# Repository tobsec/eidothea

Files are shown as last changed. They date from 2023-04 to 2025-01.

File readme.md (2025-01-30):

# EIDOTHEA

Board is developed to run a V8 Chevy Small Block engine fully sequential and provide some room to adapt for other applications.
The design is based on Proteus to be able to share the same [rusEFI](https://github.com/rusefi/rusefi) firmware.
See more details and pictures in the rusEFI Forum: [https://www.rusefi.com/forum/viewtopic.php?t=2559](https://www.rusefi.com/forum/viewtopic.php?t=2559)

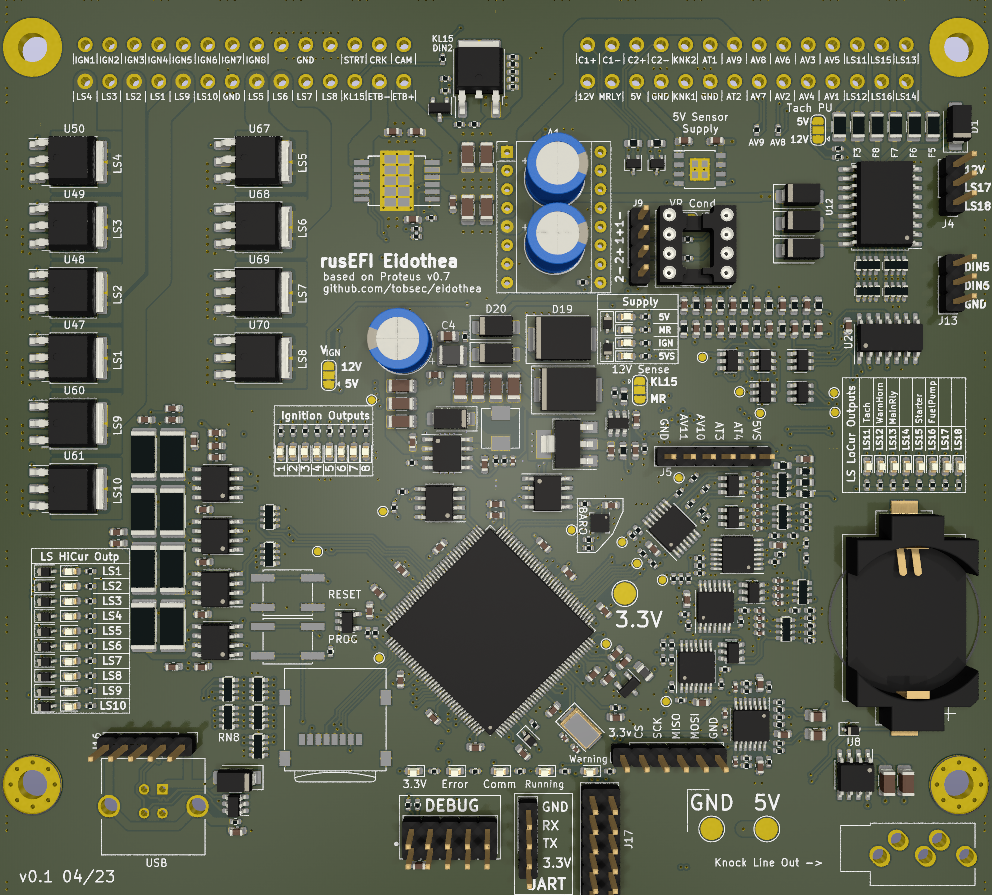
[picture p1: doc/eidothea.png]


# Hardware Features

## Microcontroller

- STM32F427ZGT6
    - 180 MHz ARM Cortex-M4
    - 1MB flash
    - 256 KB SRAM
    - LQFP144 package

- Also fully compatible with several STM32F7 parts, including the STM32F767ZI, used on v0.1 and v0.2, as well as STM32F429ZIT6.

## Connectors

Sicma 56 connector and weatherproof case available at [AliExpress](https://aliexpress.com/item/32857771975.html)

## Connectivity

- 2x CAN bus
- USB 2.0 full speed (12 mbit/s), on-board or wired to connector for sealed applications
- [10-pin, 2.54mm Cortex debug header](http://infocenter.arm.com/help/topic/com.arm.doc.faqs/attached/13634/cortex_debug_connectors.pdf)

## Outputs

- 10x 7A low-side outputs
- 8x 0.5A low-side outputs (2x internal)
- 8x 5V ignition (or general purpose) outputs
- H-bridge for electronic throttle (can use external A4988 stepper module alternatively)

## Inputs

- 11x Analog voltage inputs (2x internal)
- 4x Analog temperature (5V pullup) inputs (2x internal)
- 2x VR crank/cam/vehicle speed inputs via adapter board
- 6x hall cam/crank or digital input (2x internal)
- 2x onboard knock sensing

## Power Supply

- Full operation from 6-24v supply
- Limited operation from 4-6v
- 5V sensor supply, 150mA, fully protected

## For generating JLC PCB files install adapted KiCad Plugin
https://github.com/tobsec/JLC-Plugin-for-KiCad/tree/2.3.0-adapt

## Known issues
- Main relay can only be powered from a high current low-side output (don't run it as documented from a low-side output LS13, it will not work as the relay coil always back feeds some power to the 12V_MR rail)

## Pinout considerations
- Rework analog voltage input 2 (AV2) from pull-down to 2.7k pull-up for using it as a third external temperature sensor input (AT)
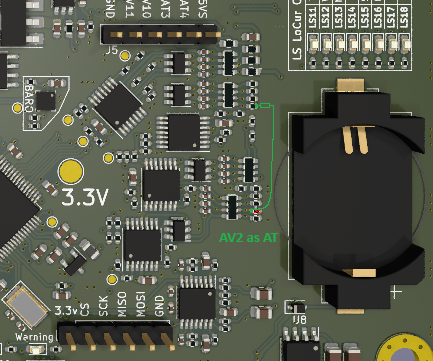
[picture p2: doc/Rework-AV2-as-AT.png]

- Rework digital input 3 (DIGITAL_3) from pull-up to pull-down to use it for starter button/switch
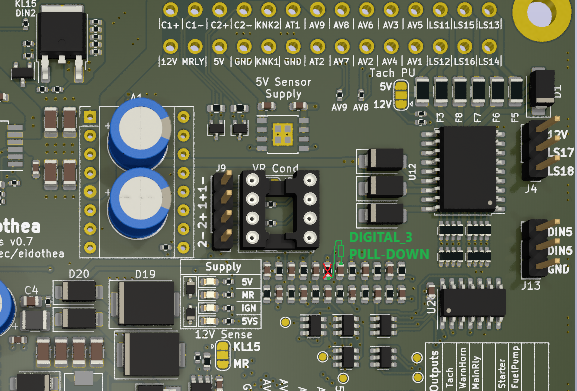
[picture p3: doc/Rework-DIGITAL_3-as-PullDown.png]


## Pinout
| No. | Pin | Description | IN / OUT | Function | Type | Drive / Signal Voltage | Notes |
|-----|---|---|---|---|---|---|---|
| 1 | IGN1 | Ignition Trigger 1 | OUT | Gate Driver IC | Low Current | 5V / 12V_MR | Default 5V |
| 2 | IGN2 | Ignition Trigger 2 | OUT | Gate Driver IC | Low Current | 5V / 12V_MR | Default 5V |
| 3 | IGN3 | Ignition Trigger 3 | OUT | Gate Driver IC | Low Current | 5V / 12V_MR | Default 5V |
| 4 | IGN4 | Ignition Trigger 4 | OUT | Gate Driver IC | Low Current | 5V / 12V_MR | Default 5V |
| 5 | IGN5 | Ignition Trigger 5 | OUT | Gate Driver IC | Low Current | 5V / 12V_MR | Default 5V |
| 6 | IGN6 | Ignition Trigger 6 | OUT | Gate Driver IC | Low Current | 5V / 12V_MR | Default 5V |
| 7 | IGN7 | Ignition Trigger 7 | OUT | Gate Driver IC | Low Current | 5V / 12V_MR | Default 5V |
| 8 | IGN8 | Ignition Trigger 8 | OUT | Gate Driver IC | Low Current | 5V / 12V_MR | Default 5V |
| 9 | GND | GND | IN | Supply | - | - | - |
| 10  | GND | GND | IN | Supply | - | - | - |
| 11  | GND | GND | IN | Supply | - | - | - |
| 12  | DIGITAL_3 | Start Switch/Button Signal | IN | Digital In 12V | Schmitt Trigger  | PullDown | Rework to PullDown |
| 13  | DIGITAL_VR_1 | Crank Sensor | IN | HALL / VR In | Schmitt Trigger  | PullUp 5V | Default HALL (opt. VR Cond. Circuit) |
| 14  | DIGITAL_VR_4 | Cam Sensor | IN | HALL / VR In | Schmitt Trigger  | PullUp 5V | Default HALL (opt. VR Cond. Circuit) |
| 15  | LS4 | Injector 4 | OUT | Low Side Switch | High Current 7A  | - | - |
| 16  | LS3 | Injector 3 | OUT | Low Side Switch | High Current 7A  | - | - |
| 17  | LS2 | Injector 2 | OUT | Low Side Switch | High Current 7A  | - | - |
| 18  | LS1 | Injector 1 | OUT | Low Side Switch | High Current 7A  | - | - |
| 19  | LS9 | Spare (e.g. Boost Control) | OUT | Low Side Switch | High Current 7A  | - | - |
| 20  | LS10 | Main Relay Drive | OUT | Low Side Switch | High Current 7A  | - | - |
| 21  | GND | Knock Sensor 2 - | IN | Knock Sensing | - | - | - |
| 22  | LS5 | Injector 5 | OUT | Low Side Switch | High Current 7A  | - | - |
| 23  | LS6 | Injector 6 | OUT | Low Side Switch | High Current 7A  | - | - |
| 24  | LS7 | Injector 7 | OUT | Low Side Switch | High Current 7A  | - | - |
| 25  | LS8 | Injector 8 | OUT | Low Side Switch | High Current 7A  | - | - |
| 26  | 12V_RAW (+ DIGITAL_2) | Ignition (KL15) | IN | Supply | - | - | |
| 27  | ETB1- | ETB M- / Idle Stepper A2 | OUT | H Bridge (opt. Stepper) | - | - | - |
| 28  | ETB1+ | ETB M+ / Idle Stepper A1 | OUT | H Bridge (opt. Stepper) | - | - | - |
| 29  | CAN+ | CAN1 H | IN / OUT | O2 Sensor CAN (500kbps) | - | - | Internal 120 Ohm CAN Termination R |
| 30  | CAN- | CAN1 L | IN / OUT | O2 Sensor CAN (500kbps) | - | - | Internal 120 Ohm CAN Termination R |
| 31  | CAN2+ | CAN2 H | IN / OUT | NMEA2000 CAN (250kbps)  | - | - | Internal 120 Ohm CAN Termination R |
| 32  | CAN2- | CAN2 L | IN / OUT | NMEA2000 CAN (250kbps)  | - | - | Internal 120 Ohm CAN Termination R |
| 33  | KNOCK_2 | Knock Sensor 2 + | IN | Knock Sensing | - | - | - |
| 34  | AT1 | Water Temperature Sensor | IN | Analog Temp | - | - | - |
| 35  | AV9 | PPS2 (Idle Stepper B2) | IN (OUT) | Analog  (opt. Stepper)  | - | - | Default Pedal Position Sensor 2 |
| 36  | AV8 | PPS1 (Idle Stepper B1) | IN (OUT) | Analog  (opt. Stepper)  | - | - | Default Pedal Position Sensor 1 |
| 37  | AV6 | ETB TPS2 | IN | Analog Voltage | - | - | - |
| 38  | AV3 | Water Pressure Sensor | IN | Analog Voltage | - | - | - |
| 39  | AV5 | ETB TPS1 | IN | Analog Voltage | - | - | - |
| 40  | LS11_F | Tacho Out | OUT | Low Side + PullUp | Low Current 0.5A | 5V / 12V_MR | Default PullUp to 12V_MR |
| 41  | LS15_F | Starter Relay Drive | OUT | Low Side Switch | Low Current 0.5A | - | - |
| 42  | LS13_F | ~Main Relay Drive~ Spare | OUT | Low Side Switch | Low Current 0.5A | - | Don't use for MR! |
| 43  | 12V_MR | Power (from Main Relay) | IN | Supply | - | - | - |
| 44  | 12V_MR | Power (from Main Relay) | IN | Supply | - | - | - |
| 45  | 5V_SENSOR_1 | Sensor Supply 5V | OUT | Analog Supply 150mA | - | - | - |
| 46  | GND | Sensor GND | OUT | Analog GND | - | - | - |
| 47  | KNOCK_1 | Knock Sensor 1 + | IN | Knock Sensing | - | - | - |
| 48  | GND | Knock Sensor 1 - | IN | Knock Sensing | - | - | - |
| 49  | AT2 | Oil Temperature Sensor | IN | Analog Temp | - | - | - |
| 50  | AV7 | Fuel Pressure Sensor | IN | Analog Voltage | - | - | - |
| 51  | AV2 | IAT Sensor | IN | Analog ~Voltage~ Temp | - | - | Rework PullUp for Temp Sensing |
| 52  | AV4 | Oil Pressure Sensor | IN | Analog Voltage | - | - | - |
| 53  | AV1 | MAP Sensor | IN | Analog Voltage | - | - | - |
| 54  | LS12_F | Audio Warning Horn / MIL | OUT | Low Side Switch | Low Current 0.5A | - | - |
| 55  | LS16_F | Fuel Pump Relay Drive | OUT | Low Side Switch | Low Current 0.5A | - | - |
| 56  | LS14_F | Spare (e.g. Boost Control) | OUT | Low Side Switch | Low Current 0.5A | - | - |

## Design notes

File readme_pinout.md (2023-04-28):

# Eidothea Pinout & Wiring

1	IGN1
2	IGN2
3	IGN3
4	IGN4
5	IGN5
6	IGN6
7	IGN7
8	IGN8
9	GND
10	GND
11	GND
12	DIGITAL_3
13	DIGITAL_VR_1
14	DIGITAL_VR_4
15	LS4
16	LS3
17	LS2
18	LS1
19	LS9
20	LS10
21	GND
22	LS5
23	LS6
24	LS7
26	12V_RAW + DIGITAL_2
27	ETB1-
28	ETB1+
28	LS8
29	CAN+
30	CAN-
31	CAN2+
32	CAN2-
33	KNOCK_2
34	AT1
35	AV9
36	AV8
37	AV6
38	AV3
39	AV5
40	LS11_F
41	LS15_F
42	LS13_F
43	12V_MR
44	12V_MR
45	5V_SENSOR_1
46	GND
47	KNOCK_1
48	GND
49	AT2
50	AV7
51	AV2
52	AV4
53	AV1
54	LS12_F
55	LS16_F
56	LS14_F

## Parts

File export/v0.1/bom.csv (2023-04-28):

Designator | Footprint | Quantity | Value | LCSC Part #
BT1 | BatteryHolder_Keystone_1060_1x2032 | 1 | Battery_Cell | C70377
C1, C109, C6 | CP_Radial_D8.0mm_P3.50mm | 3 | 56u | C106564
C10, C100, C101, C110, C31, C41, C42, C43, C48, C53, C58, C63, C64, C65, C66, C69, C70, C71, C72, C73, C75, C81, C83, C85, C92, C94, C95 | 0603 | 27 | 100n | C14663
C102, C103, C104, C105, C15, C36, C8, C88, C89, C96, C97, C98, C99 | 0603 | 13 | 10n | C57112
C106, C7 | 1206 | 2 | 2.2u | C170101
C107, C108, C12, C13, C24, C25, C87, C9, C90, C91, C93 | 1206 | 11 | 10u | C13585
C11, C20, C21 | 0402 | 3 | 330p | C13533
C111, C2, C3, C30, C5, C86 | 0603 | 6 | 1u | C15849
C14, C67, C68, C74, C78, C82, C84 | 0603 | 7 | 4.7u | C19666
C16, C17 | 0805 | 2 | 3.3n | C107149
C18, C19 | 0603 | 2 | 680p | C1630
C22, C23 | 0402 | 2 | 47p | C1567
C26, C27, C28, C29, C32, C33, C34, C35, C37, C38, C39, C40 | 0603 | 12 | 1n | C1588
C4 | 0805 | 1 | 4.7u | C98192
C44, C45, C46, C47, C49, C50, C51, C52, C54, C55, C56, C57, C59, C60, C61, C62 | 0402 | 16 | 100n | C1525
C76, C77 | 0402 | 2 | 33p | C1562
C79, C80 | 0603 | 2 | 2.2u | C23630
D1, D17, D2, D3, D4, D6, D7 | D_SMA | 7 | D_Schottky | C14996
D10, D11 | D_SOD-323 | 2 | 1N5819WS | C191023
D12, D15, D21, D22, D23, D24 | 0603 | 6 | GREEN | C72043
D13, U30, U31, U32, U33, U35, U37, U55, U56, U57, U58, U71, U74, U77, U80, U83, U86, U89, U92 | 0603 | 19 | RED | C2286
D14, U72, U75, U78, U81, U84, U87, U90, U93 | 0603 | 9 | BLUE | C72041
D16 | 0603 | 1 | ORANGE | C72038
D18, U13, U15, U17, U19, U21, U23 | SOT-23-6 | 7 | SRV05-4 | C85364
D19, D5 | D_SMC | 2 | SM15T33CA | C406701
D8, D9 | SOT-323_SC-70 | 2 | PESD1CAN-UX | C152727
F3, F4, F5, F6, F7, F8 | 1206 | 6 | Polyfuse | C207035
FB1 | 0805 | 1 | Ferrite_Bead | C1015
J10 | microSD_HC_Wuerth_693072010801 | 1 | Micro_SD_Card | C164170
J14 | USB_B_921-111A1010Y10200_Vertical | 1 | USB_B | C26234
J7 | Jack_3.5mm_PJ-3250-5A | 1 | AudioJack3 | C165947
L1 | 1210 | 1 | 2.2u | C36828
L2 | MWSA0503 | 1 | 10u | C408412
Q2 | SOT-23 | 1 | 2N7002 | C8545
R1, R100, R107, R109, R118, R146, R148, R155, R156, R158, R3, R57, R58, R59, R60, R69, R70, R71, R72, R81, R82, R83, R84, R93, R94, R95, R96, R99 | 0402 | 28 | 10k | C25744
R10, R19, R20, R9 | 0402 | 4 | 33k | C25779
R101, R102, R103, R104, R105 | 0402 | 5 | 330 | C25104
R106, R157 | 0603 | 2 | 82k | C23254
R108, R11, R12, R153, R154, R17, R18 | 0402 | 7 | 100k | C25741
R110, R111, R112, R113, R114, R115, R116, R121, R131, R38, R39, R40, R41, R42, R43, R44, R45, R46, R47, R48 | 0402 | 20 | 2k7 | C138017
R117, R119, R140, R141, R142, R143, R144, R145, R150, R151, R152 | 0402 | 11 | 0 | C17168
R120, R130, R137, R139, R147, R149, R25, R26, R31, R32, R33, R34, R35, R36, R37, R4, R97, R98 | 0402 | 18 | 1k | C11702
R122, R123, R124, R125, R126, R127, R128, R129 | 2512 | 8 | 100 | C2907569
R13, R14, R61, R62, R63, R64, R73, R74, R75, R76, R85, R86, R87, R88 | 0402 | 14 | 470k | C25790
R132, R133, R134, R135, R21, R22, R23, R24, R27, R28, R29, R30, R49, R50, R51, R52 | 0603 | 16 | 2.7k | C13167
R15, R16, R5 | 0402 | 3 | 12k | C25752
R2 | 0402 | 1 | 1 | C25086
R53, R54, R55, R56, R65, R66, R67, R68, R77, R78, R79, R80, R89, R90, R91, R92 | 0402 | 16 | 5.6k | C25908
R6 | 0402 | 1 | 68k | C36871
R7, R8 | 0603 | 2 | 120 | C22787
RN1, RN2, RN3, RN4 | R_Array_Convex_4x0603 | 4 | 10k | C29718
RN10, RN11, RN12, RN13, RN14, RN15, RN5, RN6, RN7, RN8, RN9 | R_Array_Convex_4x0603 | 11 | 1k | C20197
SW1, SW2 | SW_SPST_EVQQ2 | 2 | SW_Push | C318884
U1 | Infineon_PG-DSO-8-43 | 1 | TLS115 | N/A
U10, U14, U9 | SOT-23-6 | 3 | SN74LVC2G17DBVR | C10429
U11, U2, U38, U39, U40, U45, U46, U59, U63, U64, U65, U66 | D_SOD-323 | 12 | 1N4148WS | C2128
U12 | SOIC-18W_7.5x11.6mm_P1.27mm | 1 | TBD62083AFWG
U16, U18, U20, U22, U7 | TSSOP-14_4.4x5mm_P0.65mm | 5 | MCP6004 | C50282
U24 | SOT-23 | 1 | REF3033 | C36658
U25 | ST_HLGA-10_2.5x2.5mm_P0.6mm_LayoutBorder3x2y | 1 | LPS25HB | C94049
U26 | LQFP-144_20x20mm_P0.5mm | 1 | STM32F427ZGTx | C117816
U27 | SOT-23-6 | 1 | USBLC6-2SC6 | C7519
U29 | SOT-23-5 | 1 | MAX823 | C239902
U3 | SOIC-8-1EP_3.9x4.9mm_P1.27mm_EP2.29x3mm | 1 | LMR14020 | C187824
U36 | Infineon_PG-DSO-12-9_ThermalVias | 1 | TLE9201SG | C112633
U4, U5 | SOIC-8_3.9x4.9mm_P1.27mm | 2 | TJA1051T-3 | C6952
U41, U42, U43, U44 | SOIC-8_3.9x4.9mm_P1.27mm | 4 | MIC4427 | C20551
U47, U48, U49, U50, U60, U61, U67, U68, U69, U70 | TO-252-3_TabPin2 | 10 | VND7NV04TR-E | C262999
U6 | SOT-223-3_TabPin2 | 1 | AMS1117-3.3 | C6186
U8 | SOIC-8_3.9x4.9mm_P1.27mm | 1 | MCP6002-xSN | C7377
Y1 | Crystal_SMD_5032-2Pin_5.0x3.2mm | 1 | 8MHz | C115962

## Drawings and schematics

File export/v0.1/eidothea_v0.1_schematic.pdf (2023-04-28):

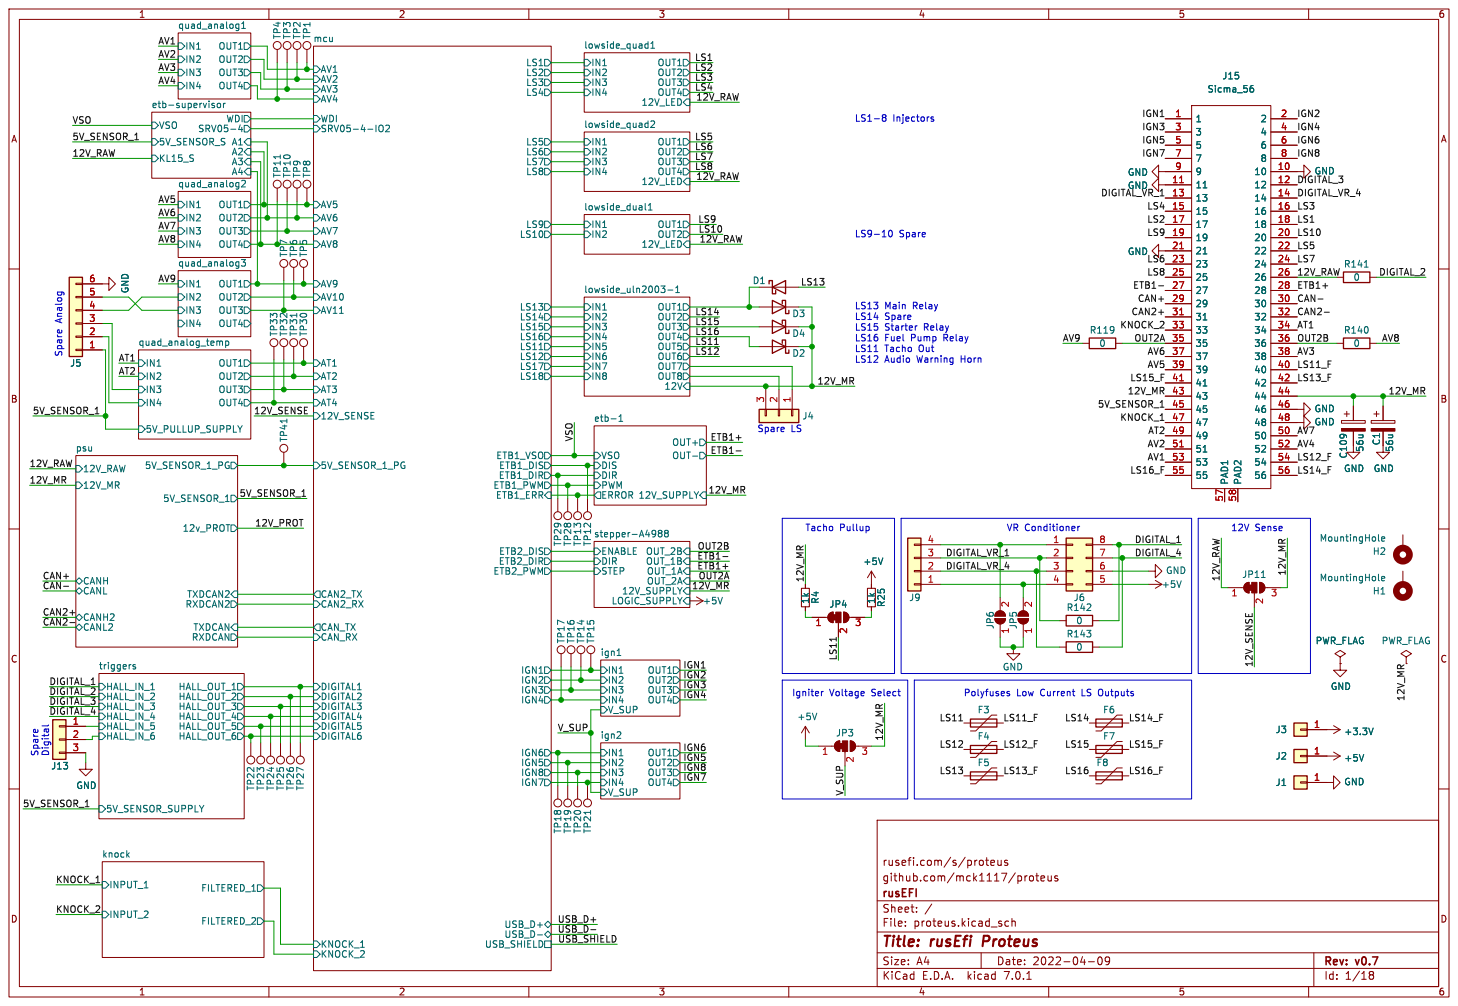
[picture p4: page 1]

LS15 Starter Relay LS16 Fuel Pump Relay LS11 Tacho Out LS12 Audio Warning Horn Spare LS

12V_SUPPLY OUT+ OUT- DIS DIR
VSO

Id: 1/18 Title: rusEfi Proteus

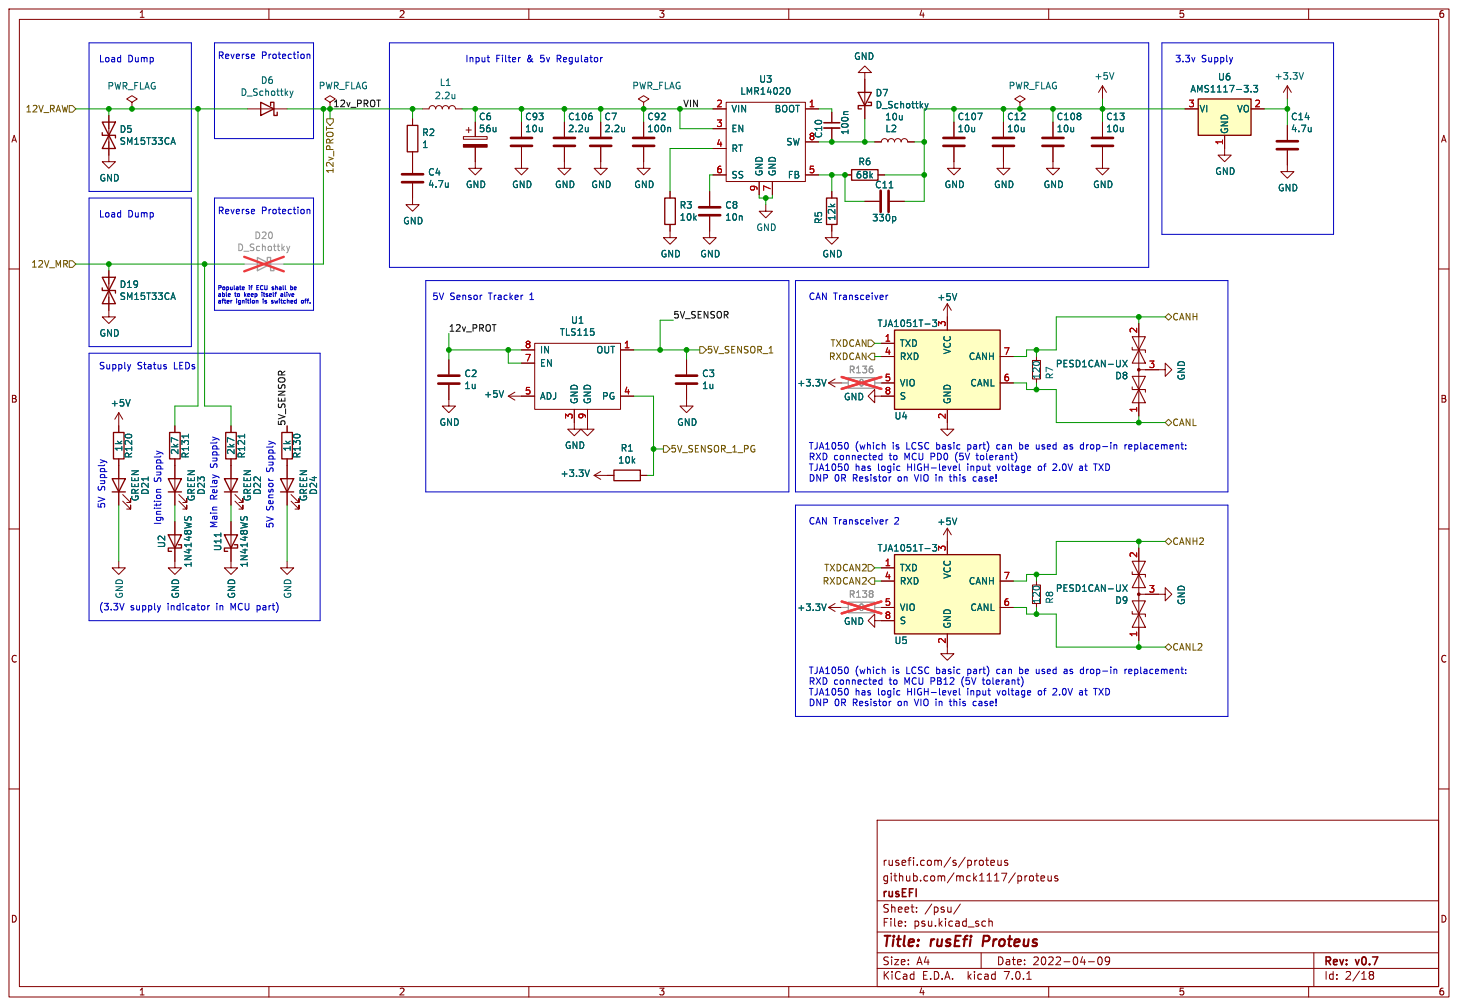
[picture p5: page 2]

3 RXD 4 VIO 5 CANL 6 CANH 7 S

DNP 0R Resistor on VIO in this case!

Id: 2/18 Title: rusEfi Proteus

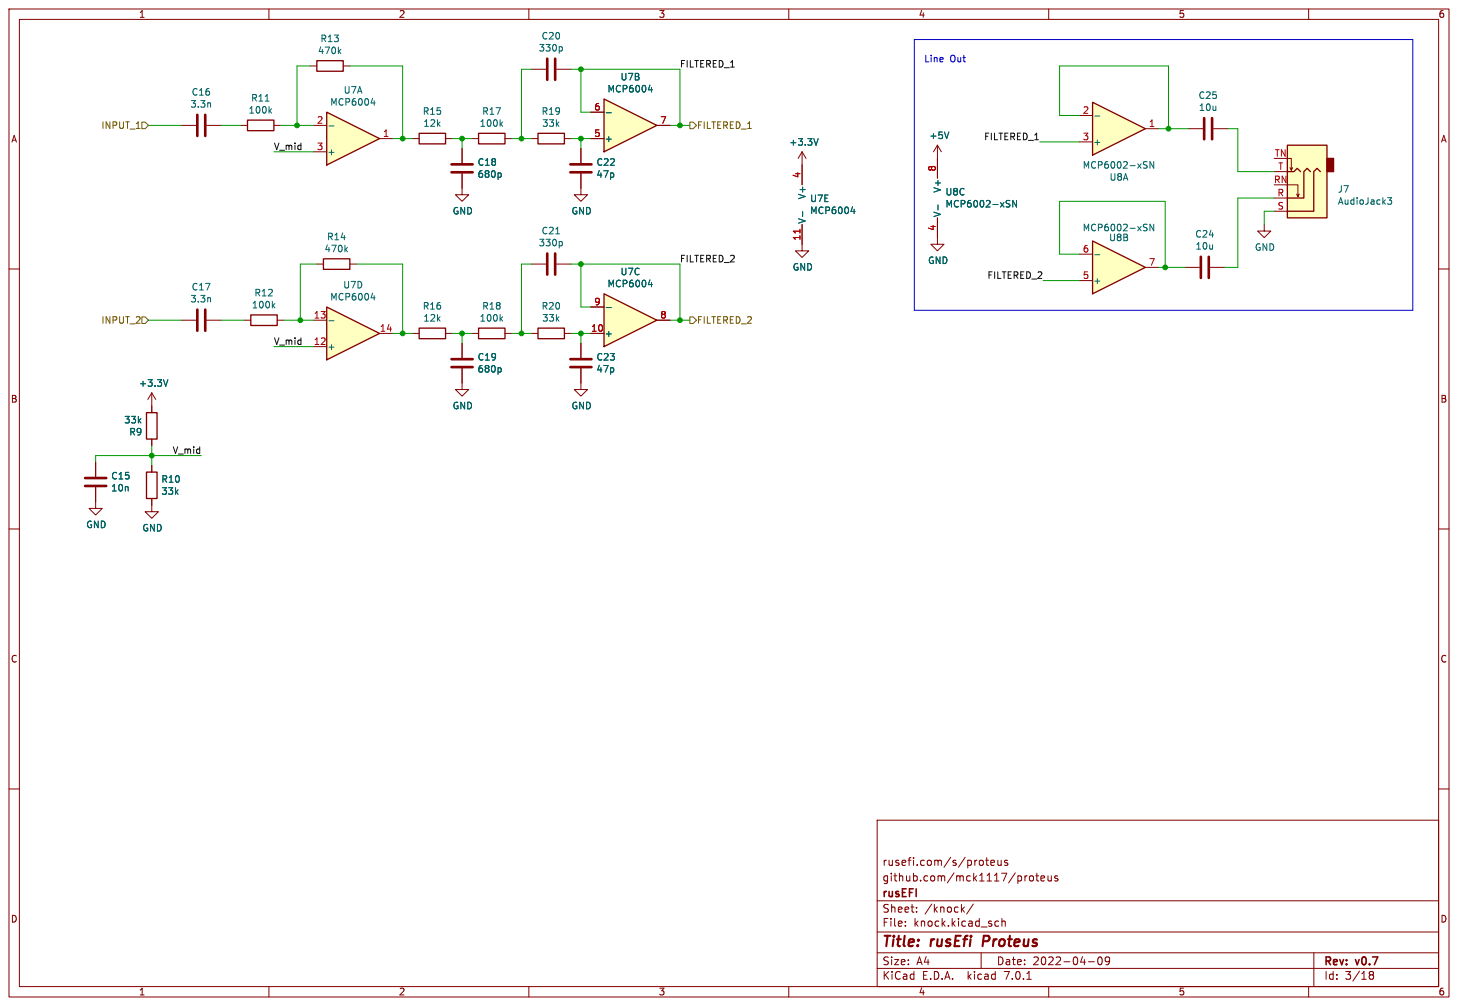
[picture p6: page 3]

Id: 3/18 Title: rusEfi Proteus

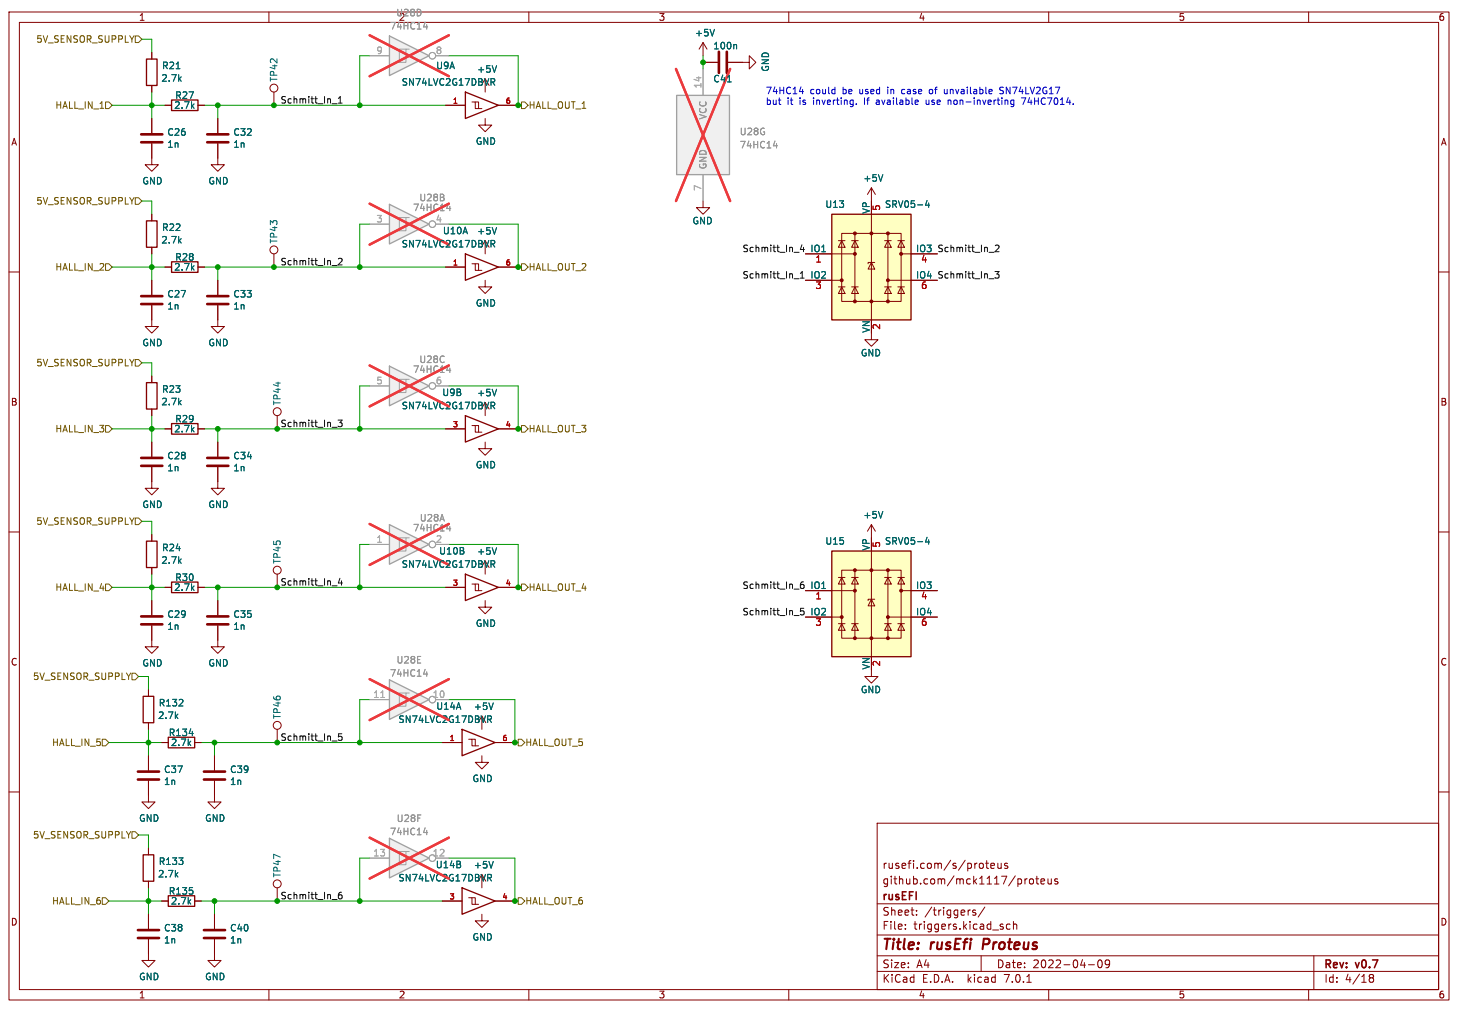
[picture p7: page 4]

File: triggers.kicad_sch Sheet: /triggers/ rusEFI github.com/mck1117/proteus

Id: 4/18 Title: rusEfi Proteus

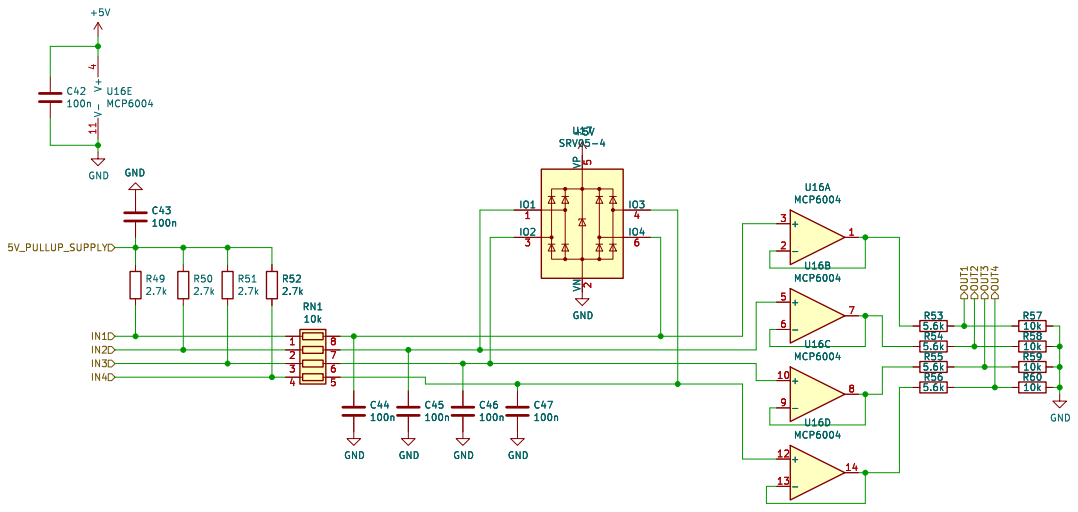
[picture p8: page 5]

File: quad_analog_pullup.kicad_sch Sheet: /quad_analog_temp/ rusEFI github.com/mck1117/proteus

Id: 5/18 Title: rusEfi Proteus

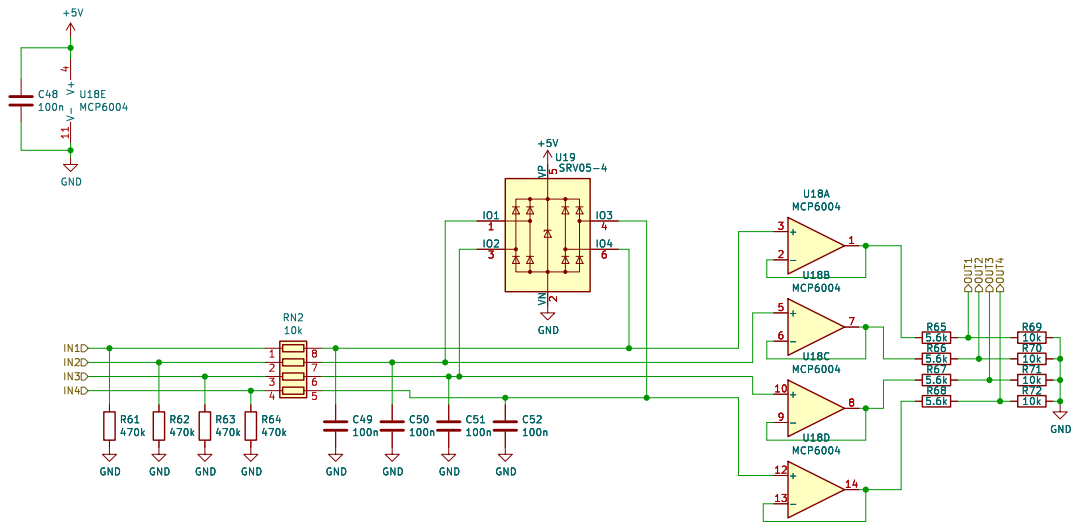
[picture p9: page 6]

File: quad_analog.kicad_sch Sheet: /quad_analog1/ rusEFI github.com/mck1117/proteus

Id: 6/18 Title: rusEfi Proteus

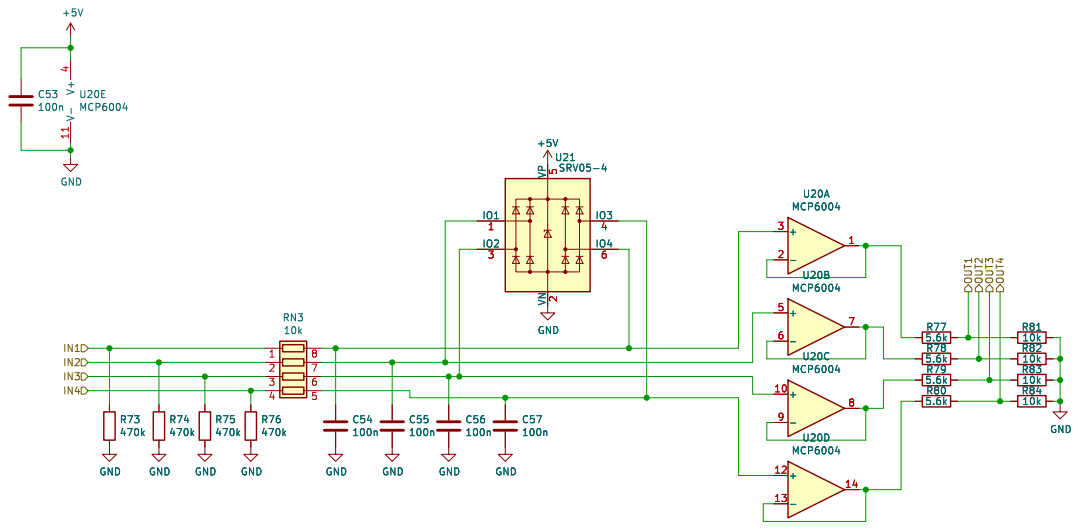
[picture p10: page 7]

rusefi.com/s/proteus GND

File: quad_analog.kicad_sch Sheet: /quad_analog2/ rusEFI github.com/mck1117/proteus

Id: 7/18 Title: rusEfi Proteus

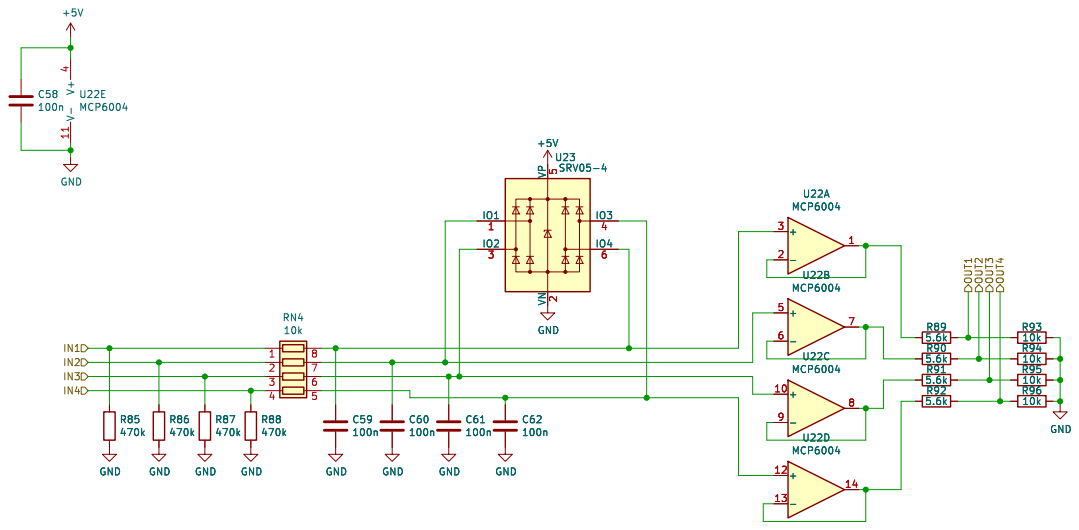
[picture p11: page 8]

File: quad_analog.kicad_sch Sheet: /quad_analog3/ rusEFI github.com/mck1117/proteus

Id: 8/18 Title: rusEfi Proteus

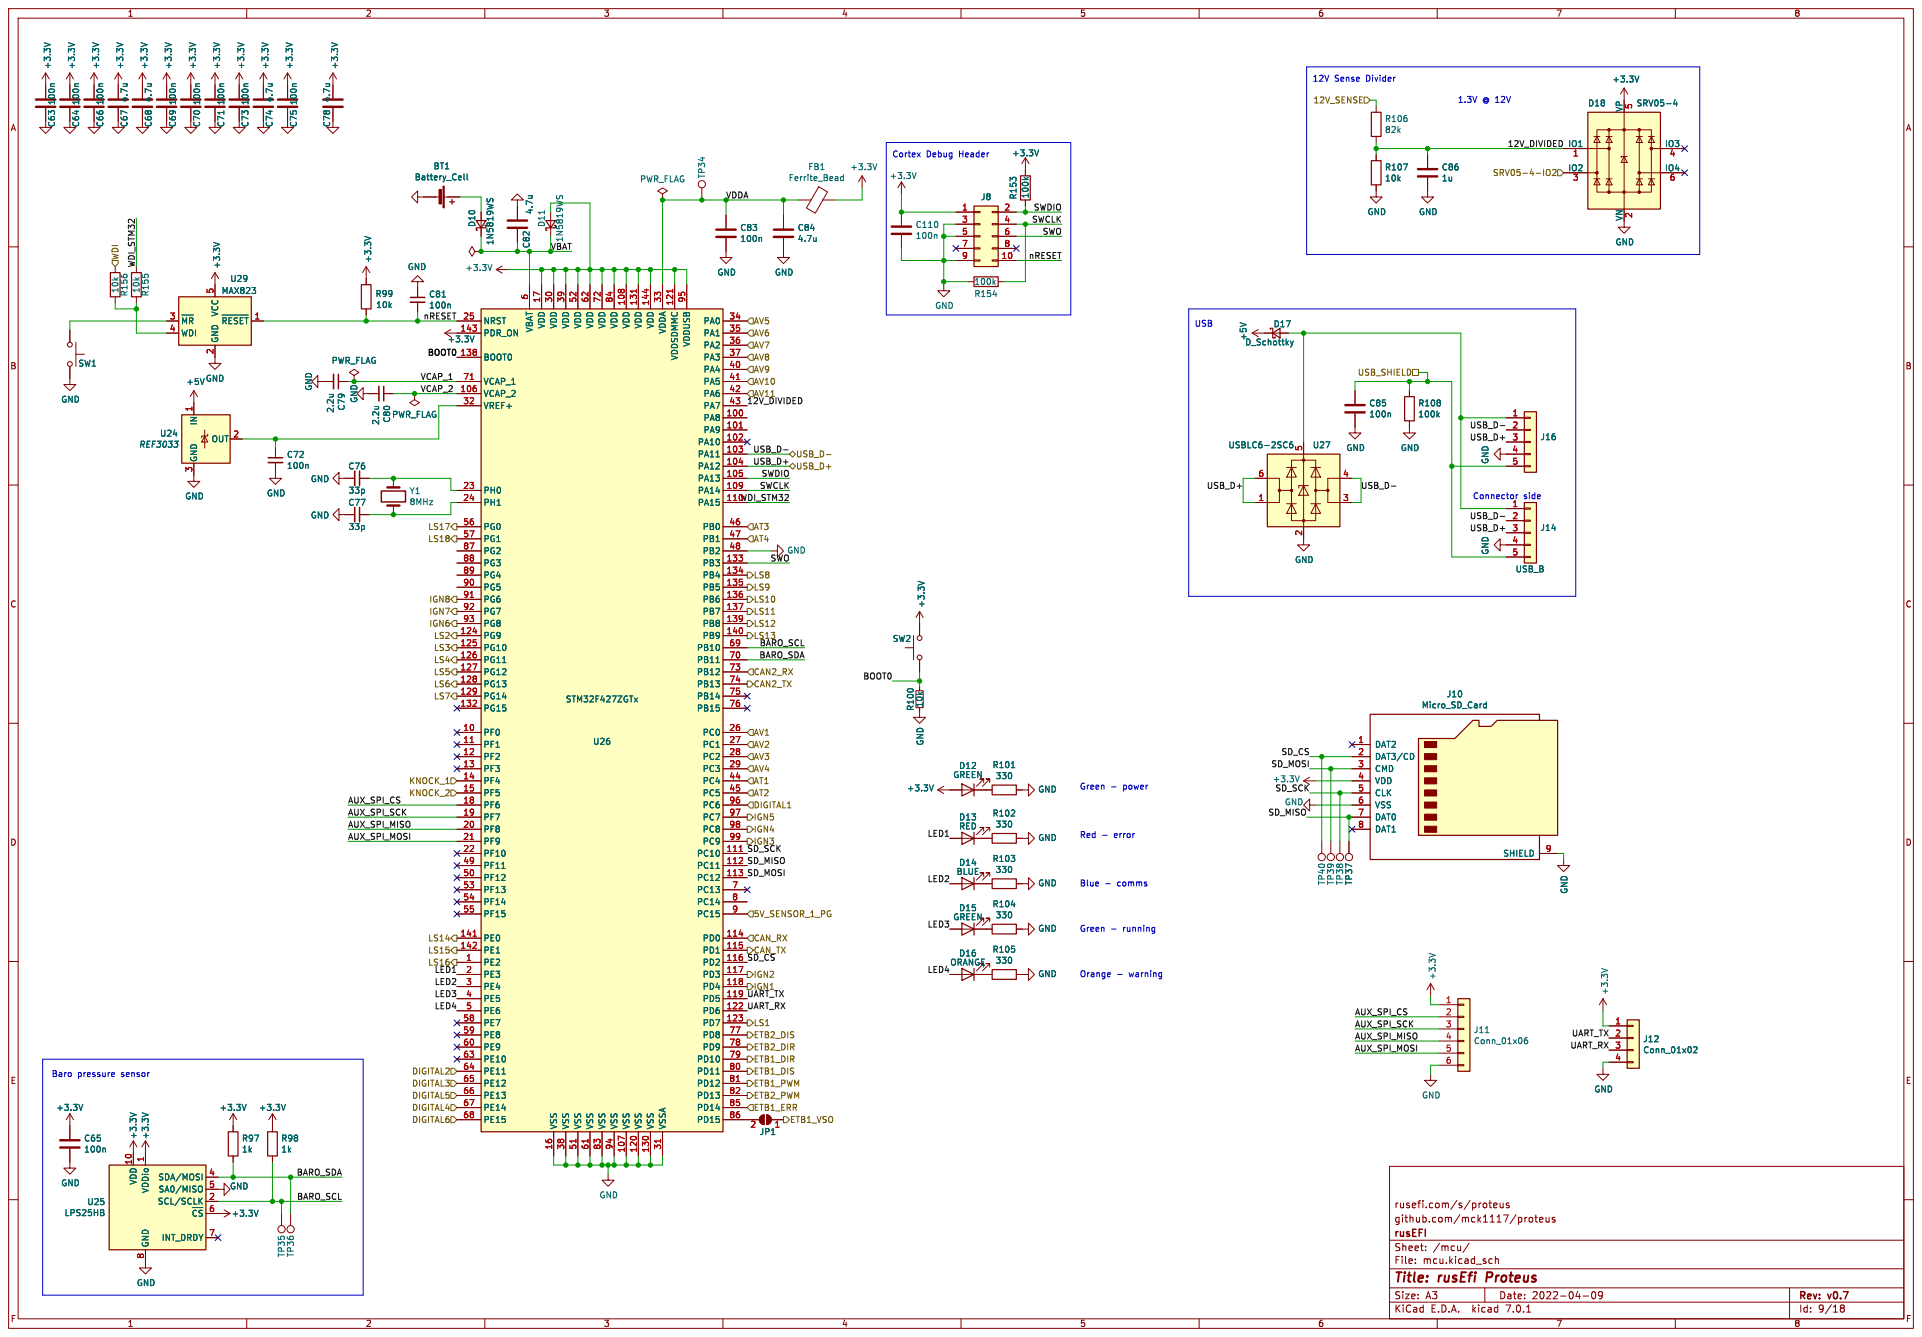
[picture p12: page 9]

3 GND GND GND GND

Orange - warning Blue - comms

1 VDD 10 SCL/SCLK 2 SDA/MOSI 4 SA0/MISO 5 ~{CS}6

rusefi.com/s/proteus
File: mcu.kicad_sch Sheet: /mcu/ rusEFI github.com/mck1117/proteus

Id: 9/18 Title: rusEfi Proteus

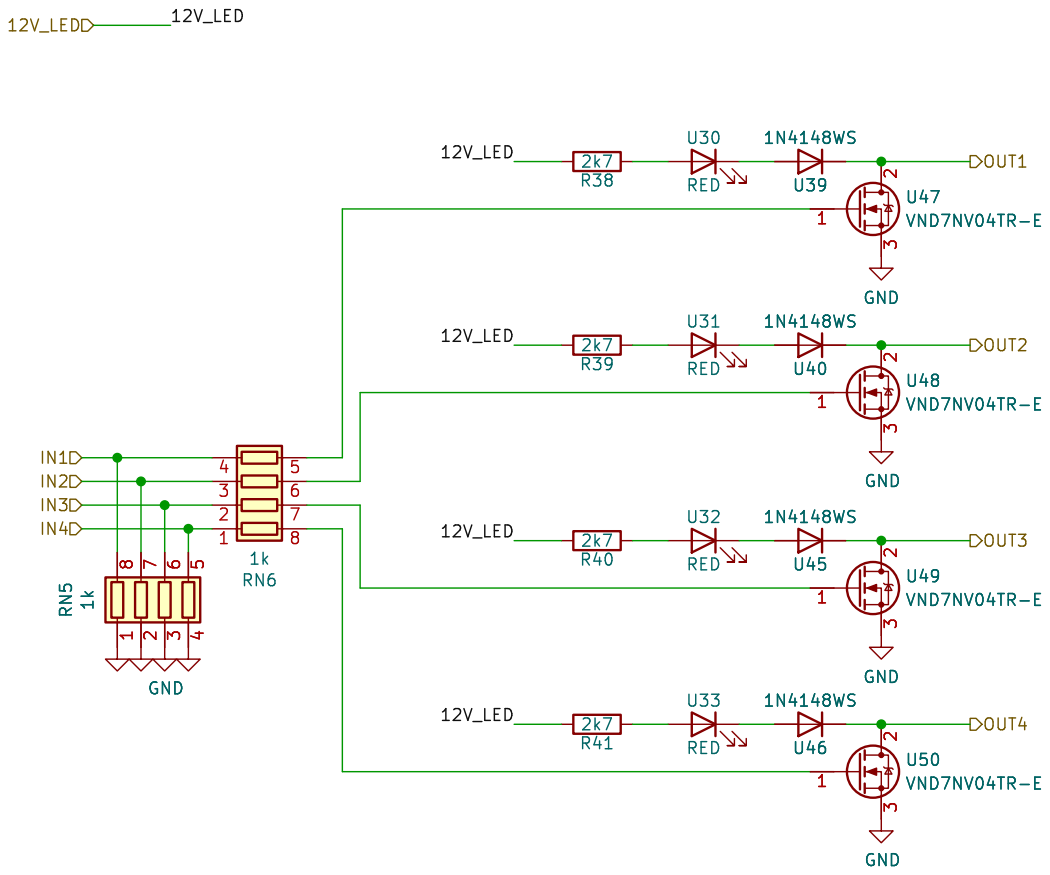
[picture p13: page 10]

rusefi.com/s/proteus
File: lowside_quad.kicad_sch Sheet: /lowside_quad1/ rusEFI github.com/mck1117/proteus

Id: 10/18 Title: rusEfi Proteus

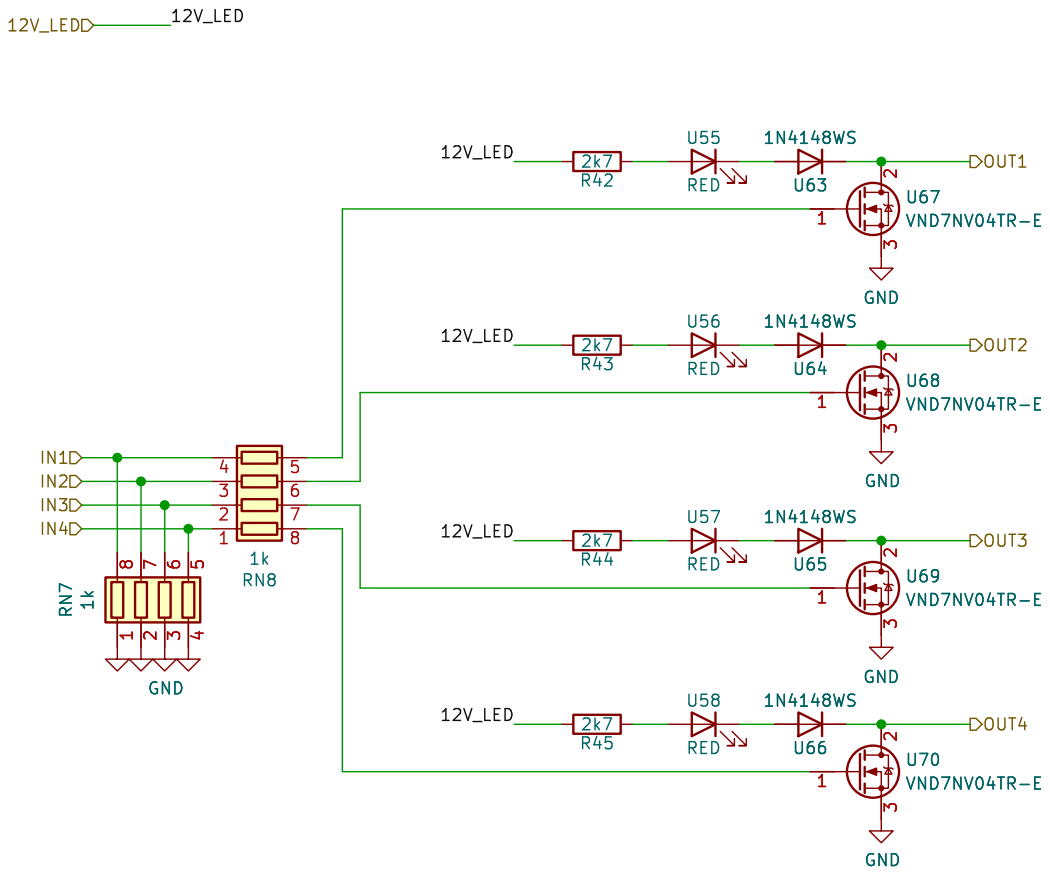
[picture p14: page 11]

rusefi.com/s/proteus
File: lowside_quad.kicad_sch Sheet: /lowside_quad2/ rusEFI github.com/mck1117/proteus

Id: 11/18 Title: rusEfi Proteus

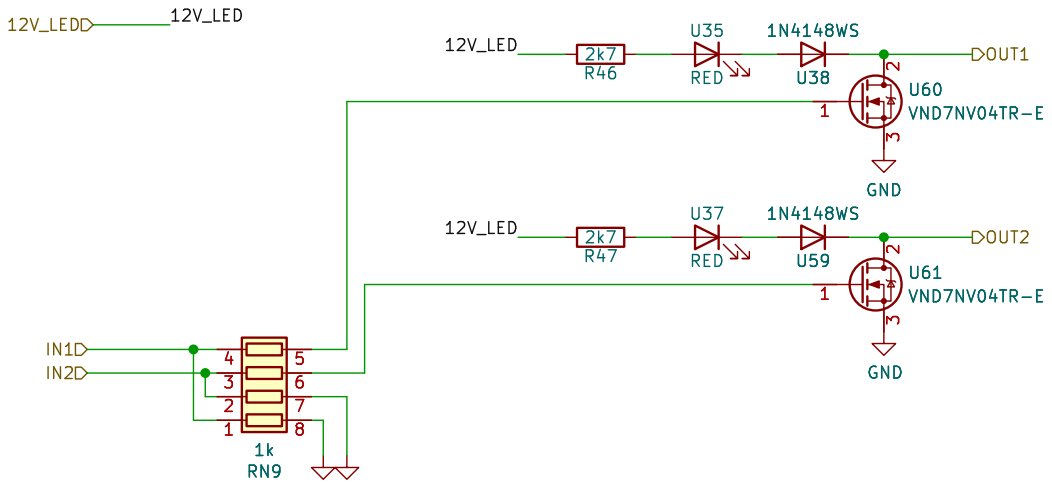
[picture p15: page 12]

rusefi.com/s/proteus
File: lowside_dual.kicad_sch Sheet: /lowside_dual1/ rusEFI github.com/mck1117/proteus

Id: 12/18 Title: rusEfi Proteus


3 3 | | 8 RN12 6 6 | I3 3
4 4 | 1k 1 | 5 5 | I2 2

2 2 | | 7 7 | I4 4
1 | | 8 | I5 5
4 4 | | 5 5 | I6 6
3 3 | | 6 6 | I7 7
2 2 | | 7 7

rusefi.com/s/proteus
File: lowside_uln2003.kicad_sch Sheet: /lowside_uln2003-1/ rusEFI github.com/mck1117/proteus

Id: 13/18 Title: rusEfi Proteus


File: etb-9201.kicad_sch Sheet: /etb-1/ rusEFI github.com/mck1117/proteus

Id: 14/18 Title: rusEfi Proteus



rusefi.com/s/proteus
File: ign4.kicad_sch Sheet: /ign1/ rusEFI github.com/mck1117/proteus

Id: 16/18 Title: rusEfi Proteus


rusefi.com/s/proteus
File: ign4.kicad_sch Sheet: /ign2/ rusEFI github.com/mck1117/proteus

Id: 17/18 Title: rusEfi Proteus


Id: 18/18 Title: File: etbsupervisor.kicad_sch Sheet: /etb-supervisor/

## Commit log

2023-04-18 Updates - Route digital inputs to connector - Add optional VR conditioner - Second Enable for H-Bridge
    [etb-9201.kicad_sch, ign4.kicad_sch, mcu.kicad_sch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]
2023-04-19 USB jack, parts and LCSC numbers, headphone jack
    [etb-9201.kicad_sch, ign4.kicad_sch, knock.kicad_sch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]
2023-04-19 Added ETB1_VSO and ETB1_ERR
    [mcu.kicad_sch, proteus.kicad_sch]
2023-04-20 Add power LEDs, silkscreen beautifying, remove U11 use U10B
    [psu.kicad_sch, triggers.kicad_sch]
2023-04-20 Several optimizations
    [etb-9201.kicad_sch, mcu.kicad_sch, proteus.kicad_sch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]
2023-04-21 Fix connector, optimize psu
    [etb-9201.kicad_sch, knock.kicad_sch, mcu.kicad_sch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]
2023-04-26 Add Stepper, fix Connector, add Testpoints, several changes
    [etb-9201.kicad_sch, ign4.kicad_sch, knock.kicad_sch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]
2023-04-28 Production optimizations, voltage superv, etb sv conn
    [bom.csv, designators.csv, etbsupervisor.kicad_sch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]
2023-04-28 Change U9,U10,U14 to SN74LVC2G17DBVR, version as ordered
    [bom.csv, designators.csv, mcu.kicad_sch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]
